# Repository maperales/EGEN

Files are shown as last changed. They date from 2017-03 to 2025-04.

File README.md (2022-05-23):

Archivos del regulador de temperatura. Electrónica General 2ºGITI Universidad de Sevilla.
=========================================================================================
En este repositorio se pueden encontrar todos los archivos necesarios para replicar el proyecto llevado a cabo en la parte 4 de la asignatura Electrónica General, de 2º curso del Grado de Ingeniera de las Tecnologías Industriales, de la Universidad de Sevilla.
  - EAGLE: archivos de Eagle para realizar la placa
  - ENERGIA: programas en energía con la funcionalidad desarrollada

En los sucesivos directorios se pueden encontrar las versiones de la placa hechas cada curso, junto con la versión del código, en caso de cambios en el código.

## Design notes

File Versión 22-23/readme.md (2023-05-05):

Nuevas versiones de la placa y del sw
=====================================
En este directorio encontraréis los ficheros del diseño realizado el curso 2022/23.

Básicamente, el cambio fundamental respecto al curso pasado es el valor (y el nombre) de las resistencias de la adaptación analógica, para ajustar al nuevo valor de la NTC utilizada (con un valor de B diferente de la de cursos anteriores). Igualmente, se han cambiado los valores de la tabla precalculada de temperatura en función del valor de ADC, para ajustar la nueva recta. Los cambios son pequeños, pero significativos.

A modo de resumen:
  - **placa2caras_23.brd**: trazado básico de pistas del diseño a partir del esquema
  - **placa2caras_23.sch**: esquema del diseño realizado
  - **placa2caras_CTO4_2023.json**: trazado de pistas definitivo, en EasyEDA, con los logos y demás.
  - **PBL_CAL.INO**: programa para calibrar la placa
  - **PBL.INO / PBL.h**: programa y librería para programar finalmente la placa

**Muy Importante: recuerda que para poder programar la placa deberás seguir los pasos que se indican en el directorio [https://github.com/maperales/EGEN/tree/master/ENERGIA]**

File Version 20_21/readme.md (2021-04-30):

Nuevas versiones de la placa y del sw
=====================================
En este directorio encontraréis los ficheros del diseño realizado el curso 2020/21. 
Como recordaréis, se ha cambiado el circuito de adaptación, usando ahora el llamado "circuito 4" desarrollado en la "tarea extra.Esto tiene una serie de
ventajas, como que se usa un único amplificador, y que éste está en modo amplificador no inversor, además de ahorrar una resistencia y simplificar el cálculo frente al circuito II. 
Por otro lado, se ha situado la NTC en la parte superior del divisor resistivo, para que el cambio de signo debido a usar un amplificador no inversor se compense. El efecto es que las ecuaciones son prácticamente iguales, y en cualquier caso al crecer la temperatura crece la tensión en el ADC. Lo único que habrá que cambiar, por tanto, es la tabla de valores de T en función de la tensión (fichero pbl.h). A modo de resumen:
  - **Placa2caras_CTO2_4.brd**: trazado de pistas del diseño
  - **Placa2caras_CTO2_4.sch**: esquema del diseño realizado
  - **placa2caras_CTO4_corregido.json**: trazado de pistas definitivo, en EasyEDA, con los logos y demás.
  - **Pbl.ino**: fichero Energia para programar el microcontrolador. Igual al del año pasado
  - **Pbl.h**: fichero de librería. Contiene la nueva tabla de valores. Éste sí ha cambiado
  - **PBL_CAL.ino**: fichero de calibración de la placa. Cambia porque incorpora en sí mismo la tabla de valores 

**Muy Importante: recuerda que para poder programar la placa deberás seguir los pasos que se indican en el directorio [https://github.com/maperales/EGEN/tree/master/ENERGIA]**

**Otra nota igual de importante: los ficheros de Eagle que se muestran aquí YA ESTÁN CORREGIDOS. Al fabricar la placa, sin embargo, se deslizó un fallo en la serigrafía y los valores de R2 y RD aparecen cambiados entre sí.**

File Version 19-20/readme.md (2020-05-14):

Nuevas versiones de la placa y del sw
=====================================
En este directorio encontraréis los ficheros del diseño realizado el curso 2019/20. 
Como recordaréis, se ha cambiado el circuito de lectura de botones, realizando la lectura ahora como una señal analógica. Esto simplifica el programa, aclarando el manejo de los botones e independizándolo de las señales K1, K2, K3 lo que permite leerlos a la velocidad que se desee. El circuito de adaptación se mantiene como en el curso pasado (circuito 2).
Por otro lado, los ficheros para la placa se han realizado en Kicad a partir de la versión en Eagle, y se incluyen en un fichero ZIP que contiene todo lo necesario (espero) para poder hacer la placa. 
A modo de resumen:
  - **PBL_1920_KiKad.zip**: Carpeta comprimida con todos los ficheros para el desarrollo del prototipo
  - **Pbl.ino**: fichero Energia para programar el microcontrolador. Igual al del año pasado
  - **Pbl.h**: fichero de librería. Contiene la nueva tabla de valores. Éste sí ha cambiado
  - **PBL_CAL.ino**: fichero de calibración de la placa. Cambia porque incorpora en sí mismo la tabla de valores 

**Muy Importante: recuerda que para poder programar la placa deberás seguir los pasos que se indican en el directorio [https://github.com/maperales/EGEN/tree/master/ENERGIA]**

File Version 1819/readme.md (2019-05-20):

Nuevas versiones de la placa y del sw
=====================================
En este directorio encontraréis los ficheros del diseño realizado el curso 2018/19. 
Como recordaréis, se ha cambiado el circuito de adaptación, usando ahora el llamado "circuito 2" en los apuntes. Esto tiene una serie de
ventajas, como que se usa un único amplificador, y que éste está en modo amplificador no inversor. El inconveniente fundamental
es que necesita una resistencia más. 
Por otro lado, se ha situado la NTC en la parte superior del divisor resistivo, para que el cambio de signo debido a usar un amplificador no inversor se compense. El efecto es que las ecuaciones son prácticamente iguales, y en cualquier caso al crecer la temperatura crece la tensión en el ADC. Lo único que habrá que cambiar, por tanto, es la tabla de valores de T en función de la tensión (fichero pbl.h). A modo de resumen:
  - **Placa2caras_CTO2_2.brd**: trazado de pistas del diseño
  - **Placa2caras_CTO2_2.sch**: esquema del diseño realizado
  - **Pbl.ino**: fichero Energia para programar el microcontrolador. Igual al del año pasado
  - **Pbl.h**: fichero de librería. Contiene la nueva tabla de valores. Éste sí ha cambiado
  - **PBL_CAL.ino**: fichero de calibración de la placa. Cambia porque incorpora en sí mismo la tabla de valores 

**Muy Importante: recuerda que para poder programar la placa deberás seguir los pasos que se indican en el directorio [https://github.com/maperales/EGEN/tree/master/ENERGIA]**

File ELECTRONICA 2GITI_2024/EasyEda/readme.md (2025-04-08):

Ficheros EasyEda
================
Se incluyen los ficheros relativos al proyecto, en formato EasyEda Pro:
  - placa_sch.epro: esquemático de la placa
  - placa_pcb.epro: PCB de la placa
  - placa_gerber.zip: ficheros de fabricación (GERBER) de la placa
  - placa_BOM.html: fichero interactivo para la identificación de componentes

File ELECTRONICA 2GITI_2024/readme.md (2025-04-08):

Electrónica 2ºGITI Plan 2024
=========================================================================================
En este repositorio se pueden encontrar todos los archivos necesarios para replicar el proyecto llevado a cabo en la parte de diseño de la asignatura Electrónica, de 2º curso del Grado de Ingeniera de las Tecnologías Industriales, plan de 2024, de la Universidad de Sevilla.
  - EasyEda: archivos de EasyEda (pro) para realizar la placa
  - CCS: programas en Code Composer Studio (C) con la funcionalidad desarrollada

En los sucesivos directorios se pueden encontrar las versiones de la placa hechas cada curso, junto con la versión del código, en caso de cambios en el código.

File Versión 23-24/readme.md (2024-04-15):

Nuevas versiones de la placa y del sw
=====================================
En esta carpeta se encuentran todos los ficheros de la última versión realizada en la asignatura de Electrónica General. Con la extinción del plan de estudios, 
esta asignatura desaparecerá el curso 2023-24, siendo esta la última vez que se monta esta placa. O no, ya veremos.

El único cambio de la placa es la posición de los transistores. Se han girado para evitar la confusión que podía producirse al estar todos los pines "en línea", lo que puede llevar a colocar mal un transistor. Mínimamente también se ha cambiado el tamaño de algún pad que resultaba difícil de soldar. Finalmente, se ha incorporado un código QR para llevar directamente a esta página.

A modo de resumen:
  - **placa2caras_23.brd**: trazado básico de pistas del diseño a partir del esquema (igual que el curso pasado)
  - **placa2caras_23.sch**: esquema del diseño realizado (igual que el curso pasado)
  - **placa2caras_CTO4_2024.json**: trazado de pistas definitivo, en EasyEDA, con los logos y demás.
  - **PBL_CAL.INO**: programa para calibrar la placa
  - **PBL.INO / PBL.h**: programa y librería para programar finalmente la placa

**Muy Importante: recuerda que para poder programar la placa deberás seguir los pasos que se indican en el directorio [https://github.com/maperales/EGEN/tree/master/ENERGIA]**

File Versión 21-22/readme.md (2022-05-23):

Nuevas versiones de la placa y del sw
=====================================
En este directorio encontraréis los ficheros del diseño realizado el curso 2021/22. 
Como recordaréis, este curso el único cambio respecto al del año pasado es la huella de un componente (el regulador de tensión) y el valor de una resistencia (la del filtro de primer orden). Por lo demás, es exactamente igual al diseño del curso pasado, por lo que el softeare no ha cambiado nada. La única novedad está en el fichero de trazado definitivo de pistas (que es donde se ha realizado el cambio de la huella) y en el esquema (cambio del valor de R8). Por tanto, no se incluyen en esta carpeta los ficheros de programación: usen los del curso anterior.  

A modo de resumen:
  - **placa2caras_22.brd**: trazado de pistas del diseño
  - **placa2caras_22.sch**: esquema del diseño realizado
  - **placa2caras_CTO4_2022.json**: trazado de pistas definitivo, en EasyEDA, con los logos y demás.

**Muy Importante: recuerda que para poder programar la placa deberás seguir los pasos que se indican en el directorio [https://github.com/maperales/EGEN/tree/master/ENERGIA]**

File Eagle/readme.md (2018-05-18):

Versión actual de los archivos de Eagle de la placa
==================================================
La placa está fabricada a doble cara, con taladros metalizados y un ancho de pista estndar de 16mils. En estas condiciones, resulta 
un poco compleja de fabricar con métodos *artesanales*. Los ficheros incluidos son:
- placa2caras_v1718.sch: esquema de la placa
- placa2caras_v1718.brd: rutado de la placa
- placa2caras_v1718_TOP.pdf: impresión de la cara superior, en pdf sin escalar ni hacer *mirror*.
- placa2caras_v1718_BOTT.pdf: impresión de la cara inferior, en pdf, sin escalar pero con  *mirror*
- placa2caras_v1718_TSILK.pdf: serigrafía de la cara superior, en pdf sin escalar ni hacer *mirror*.
- placa2caras_v1718_BSILK.pdf: serigrafí de la cara inferior, en pdf, sin escalar pero con  *mirror*
- - -
Las resistencias RD1..RD8 aparecen en el esquema como resistencias de 220 ohmios, aunque se pueden usar de 100 ohmios.

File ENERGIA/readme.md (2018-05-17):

Archivos de ENERGIA.
====================
dado lo justo que va de tamaño el programa final, se recomienda usar la versión 16 (0101E0016) de Energía. 
A partir de la siguiente se han encontrado problemas con el tamaño del código (parece que el compilador no optiimiza tanto). Dado que el código final ocupa 2011 de los 2048 bytes, cualquier cambio puede afectar. 
- - -
## Novedad: 
Se ha optimizado el código y ya cabe, incluso compilado con la versión 17. Finalmente ocupa, eso sí, 2046 de los 2048 bytes disponibles... 
- - -
La conexión entre la placa y un Launchpad G2 se hará con 4 cables hembra-hembra como se muestra en la imagen:
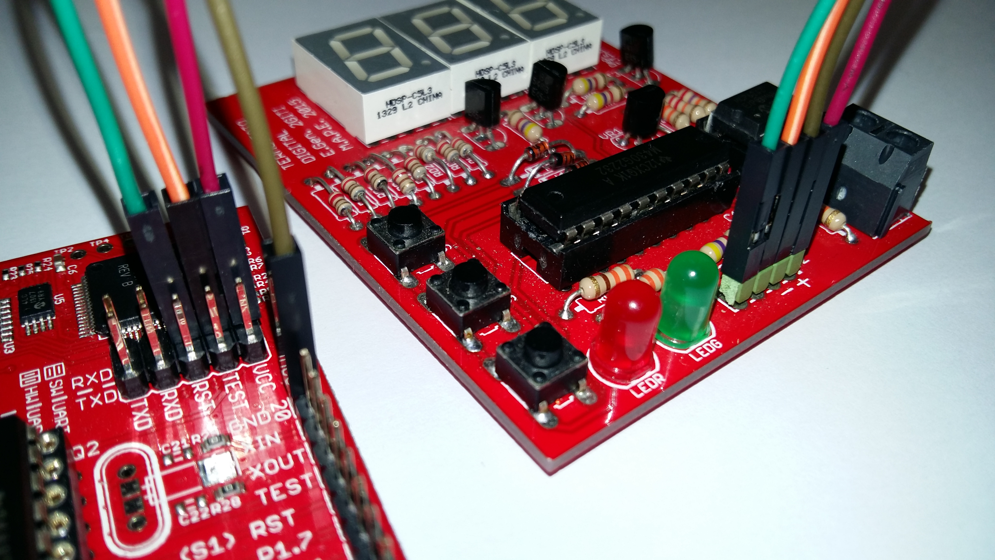
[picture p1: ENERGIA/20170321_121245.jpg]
Montaje

- - -
Para poder programar correctamente la placa, se deben seguir estos pasos:
- Descargar e instalar Energia Versión 16 [ENERGIA](http://energia.nu/download/)
- Copiar el archivo Boards.txt en el directorio \hardware\msp430\ de Energia.
- Cargar y ejecutar el Sketch PBL_CAL.ino. Anotar el offset que muestra la pantalla, y sumarlo a la variable OFFSET al principio del mismo
- Repetir el proceso hasta que el error mostrado sea 00
- Anotar el valor final de la variable OFFSET.
- Cargar el Sketch PBL.ino. En el mismo directorio debe estar el archivo PBL.h
- Modificar el valor de OFFSET según el obtenido en la calibración
- Programar la tarjeta.

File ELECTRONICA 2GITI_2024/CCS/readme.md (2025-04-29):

En este directorio se encuentran los ficheros necesarios para programar el microcontrolador
=========================================================================================
Para programar el microcontrolador se impoprtará el proyecto completo (archivo proyecto.zip). Alternativamente, se puede crear un proyecto nuevo para el microcontrolador elegido (MSP430G2232) y copiar los archivos main.c y constantes.h

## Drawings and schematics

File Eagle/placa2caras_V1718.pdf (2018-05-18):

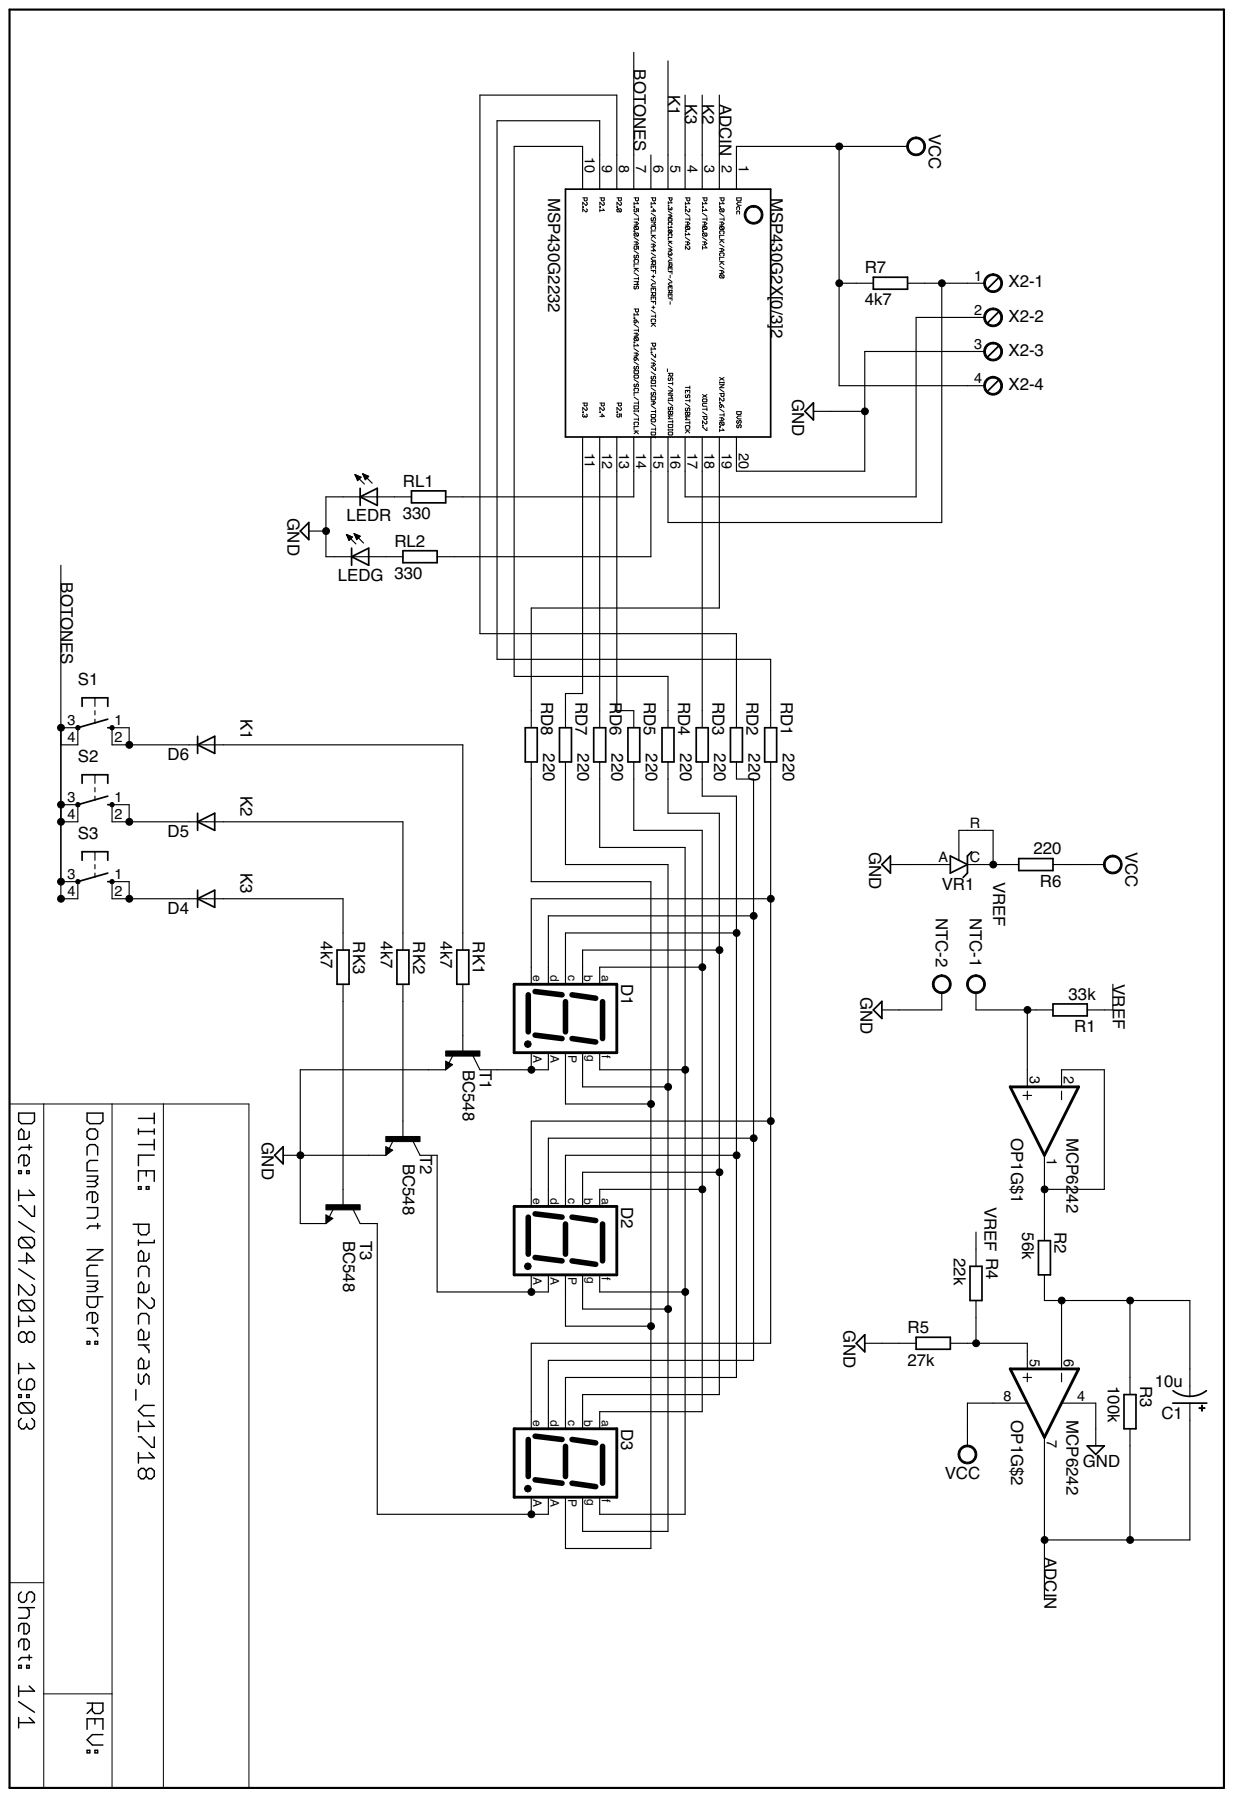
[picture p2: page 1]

MSP430G2X[0/3]2 220 220 220 220 220 220 220 220 4k7 4k7 4k7 BC548 BC548 BC548 GND GND VCC MCP6242 MCP6242 33k 56k 100k 22k 27k 220 VCC GND GND GND 10u VCC GND 330 GND 4k7 330 MSP430G2232 7654321 14151617181920 9810 131211 D1 D2 D3 RD1 RD2 RD3 RD4 RD5 RD6 RD7 RD8 RK1 RK2 RK3 T1 T2 T3 D4 D5 D6 S3 3 1 4 2 S2 3 1 4 2 S1 3 1 4 2 OP1G$1 32 1 OP1G$2 56 7 8 4R1 R2 R3 R4 R5 NTC-1 NTC-2 VR1 A CR R6 C1 LEDR LEDG RL2 R7 RL1 X2-1 1 X2-2 2 X2-3 3 X2-4 4 BOTONES BOTONES K1 K1 K2 K2 K3 K3 ADCIN ADCIN VREF VREF VREF edcba AAPgf edcba AAPgf edcba AAPgf

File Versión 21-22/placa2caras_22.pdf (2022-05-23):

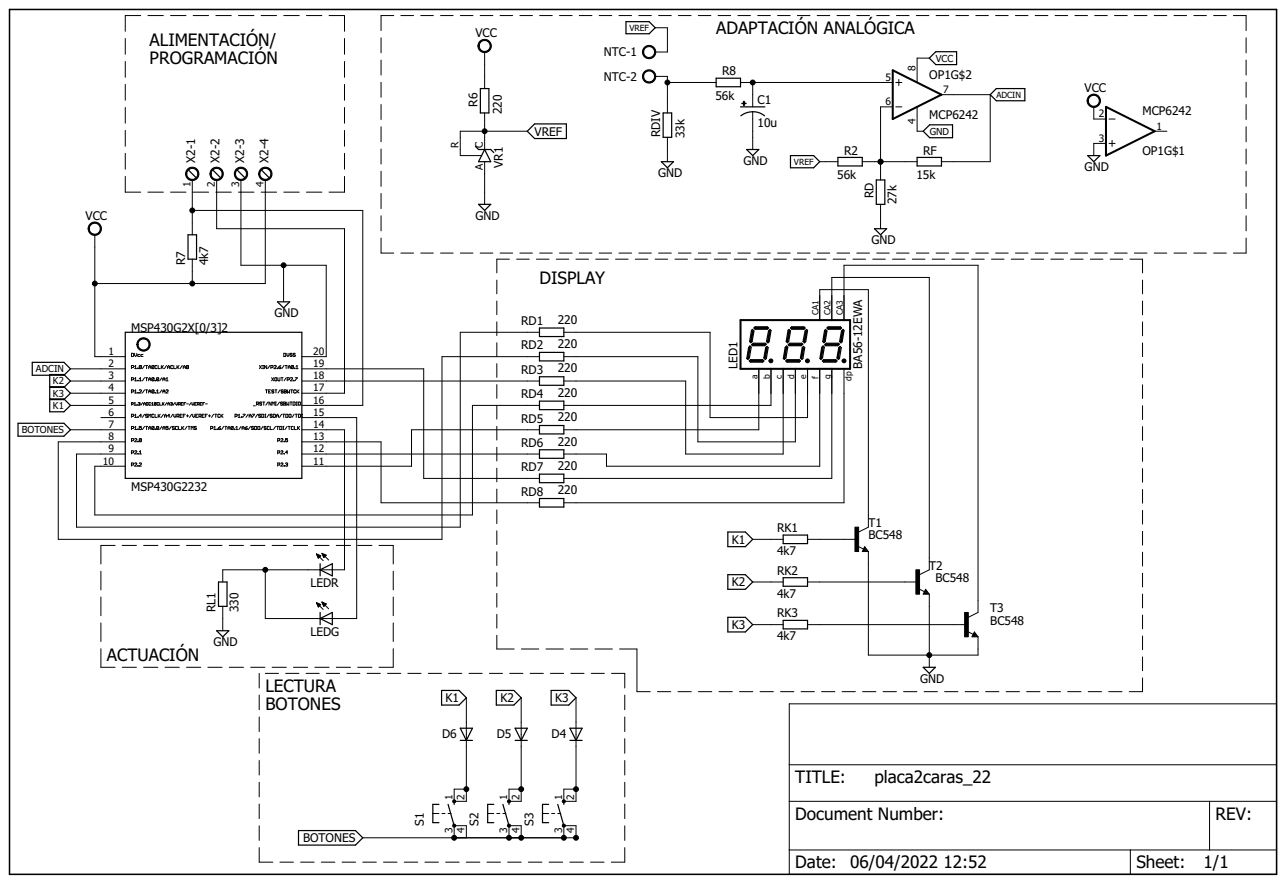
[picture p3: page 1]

18
17

9 | 12
10 | 11

Document Number: | REV:

Date: 06/04/2022 12:52 | Sheet: 1/1

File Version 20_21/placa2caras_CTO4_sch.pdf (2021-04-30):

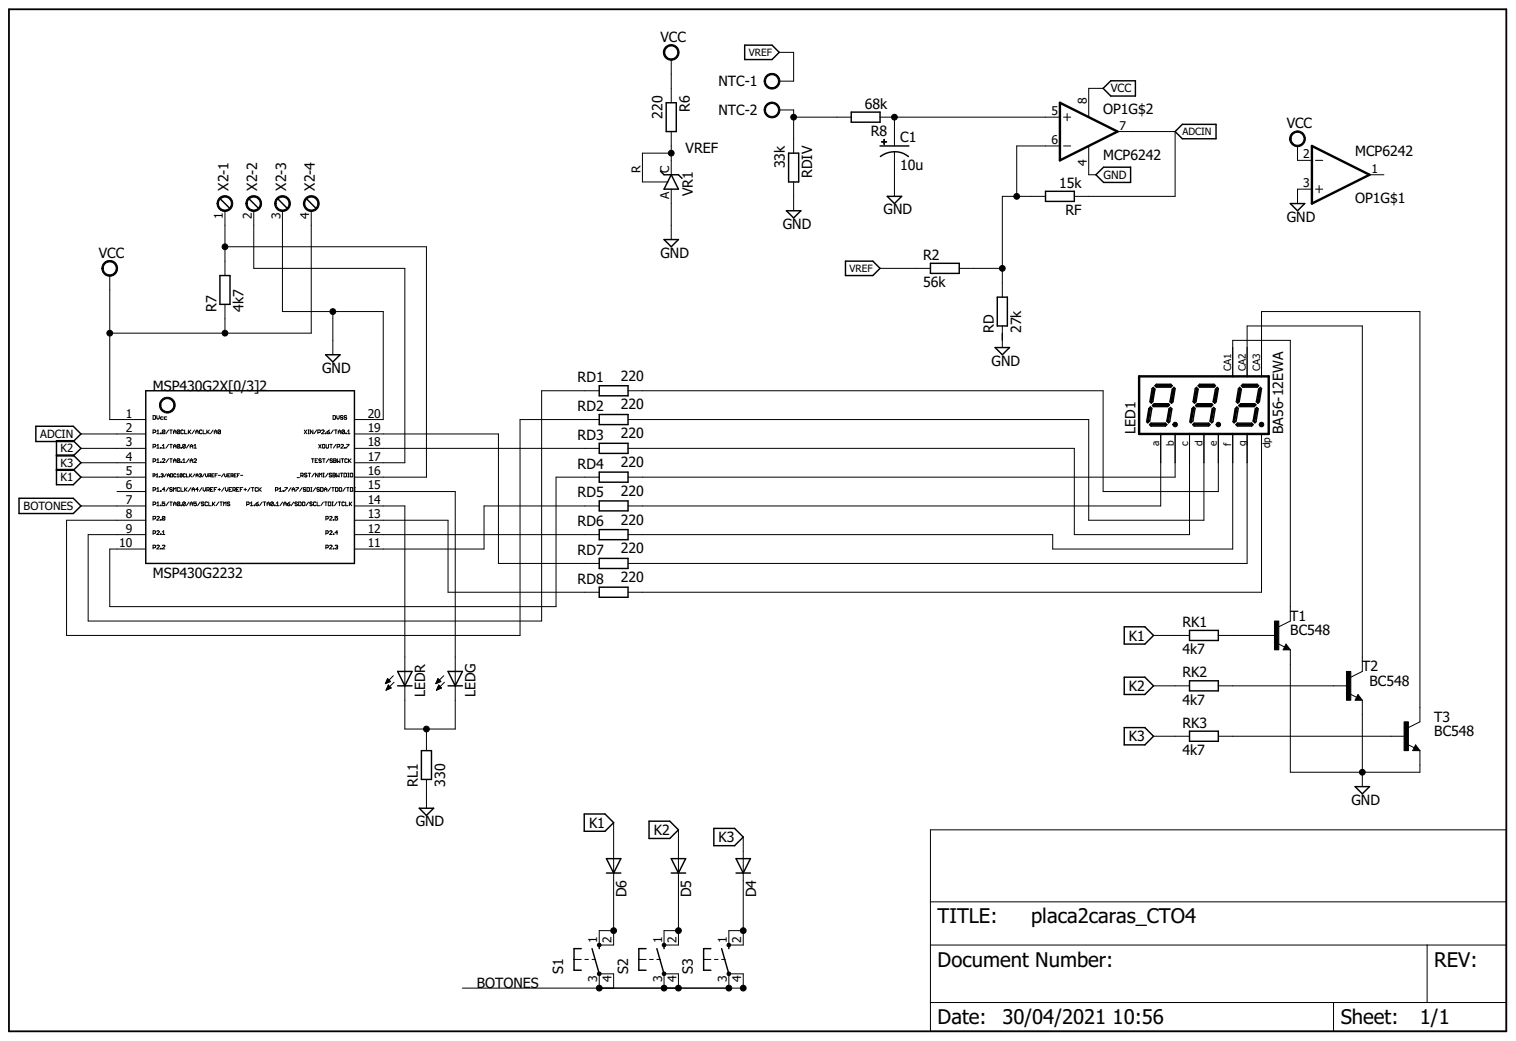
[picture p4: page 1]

18
17 | 220 RD4

Document Number: | REV:

Date: 30/04/2021 10:56 | Sheet: 1/1

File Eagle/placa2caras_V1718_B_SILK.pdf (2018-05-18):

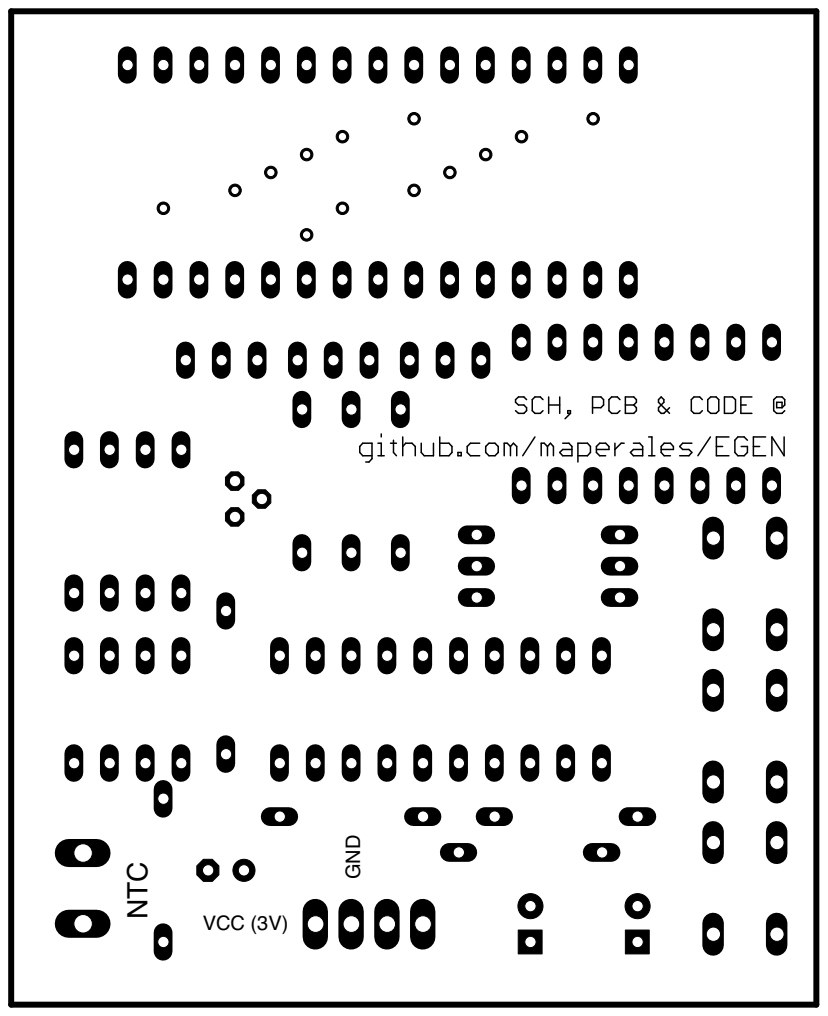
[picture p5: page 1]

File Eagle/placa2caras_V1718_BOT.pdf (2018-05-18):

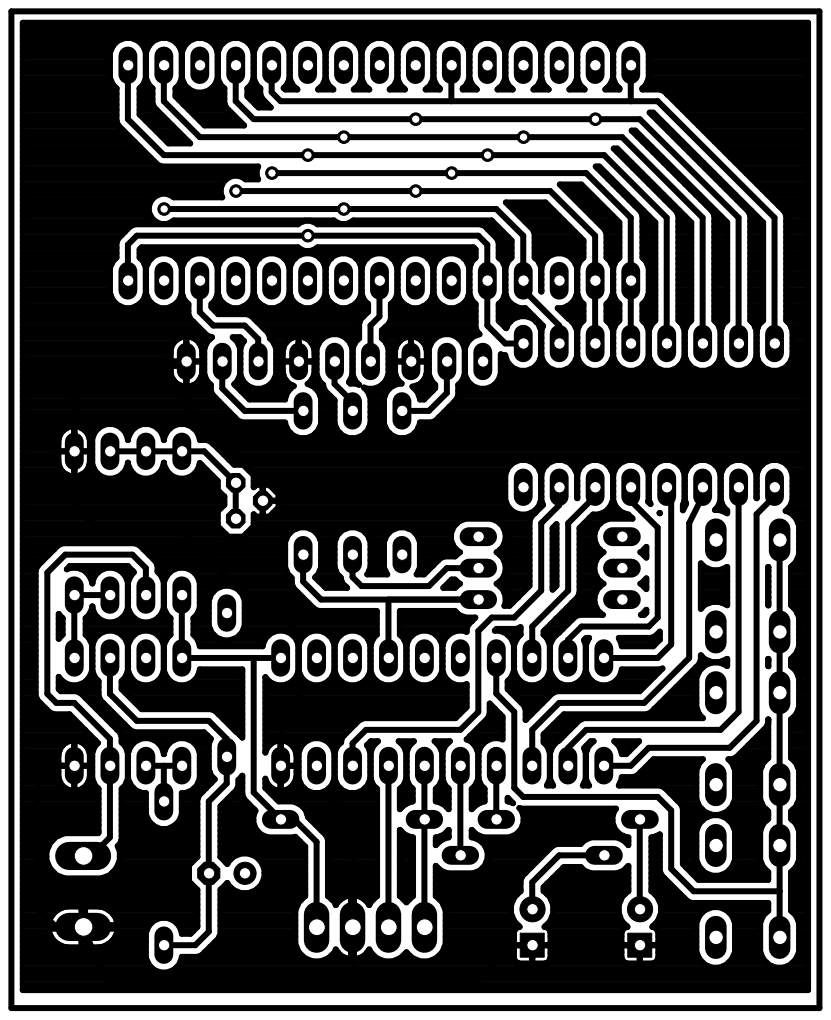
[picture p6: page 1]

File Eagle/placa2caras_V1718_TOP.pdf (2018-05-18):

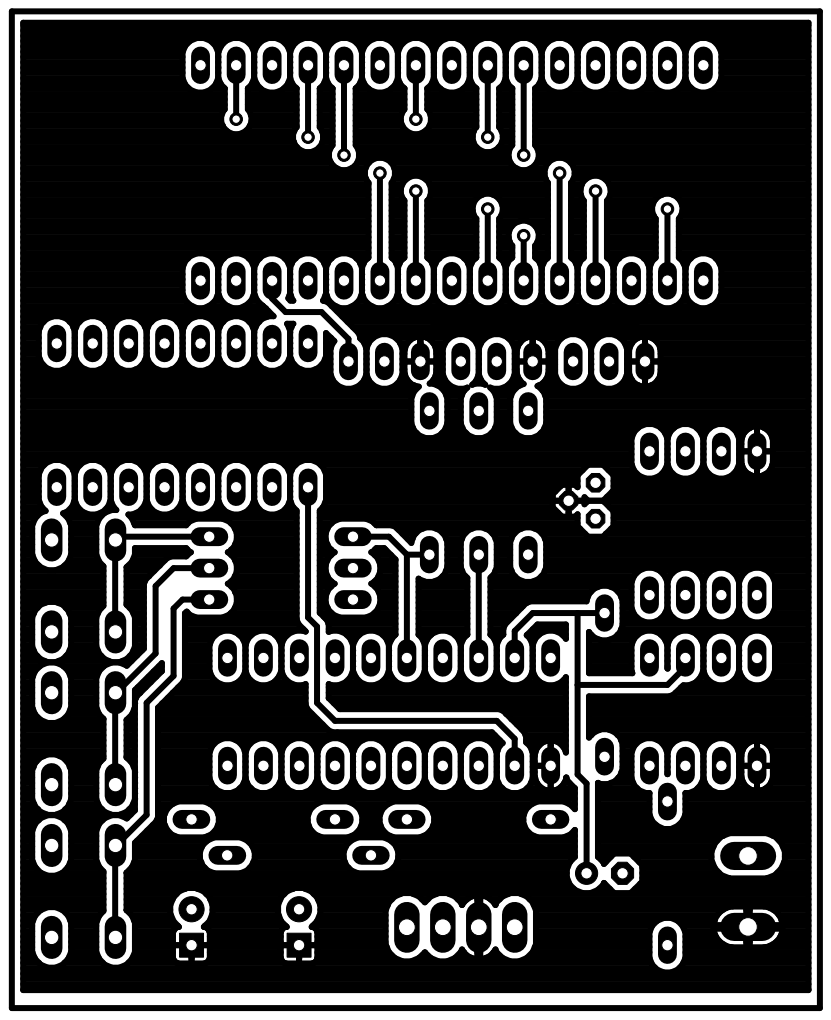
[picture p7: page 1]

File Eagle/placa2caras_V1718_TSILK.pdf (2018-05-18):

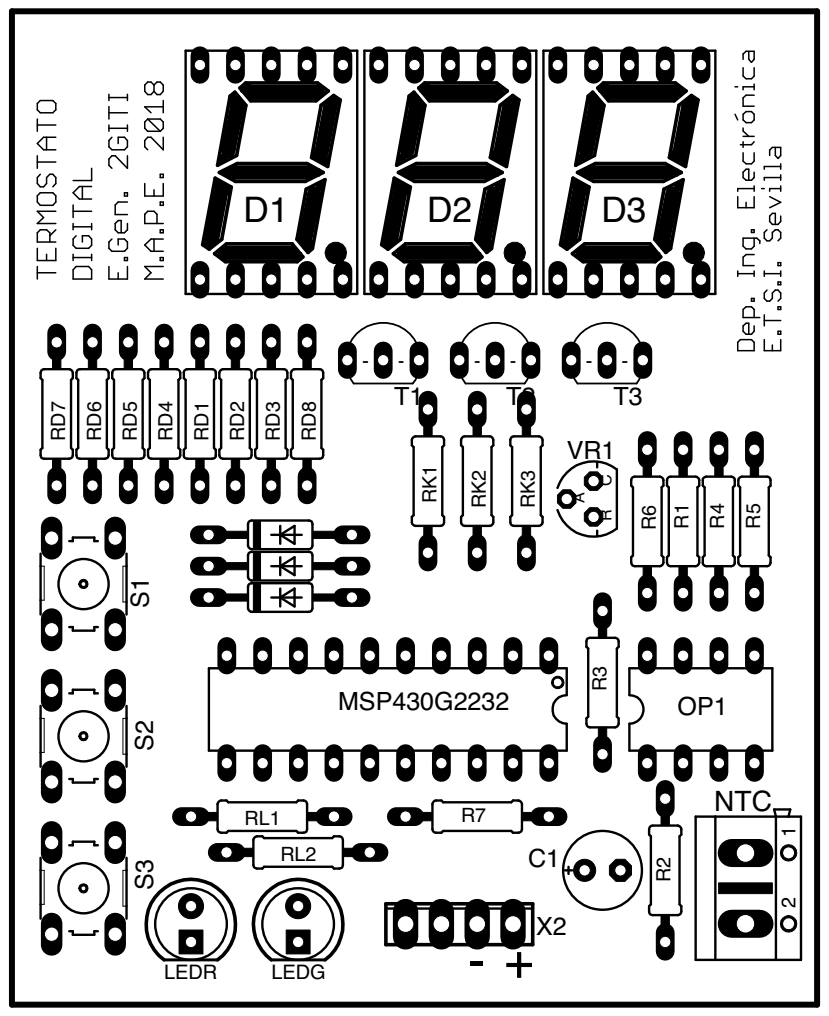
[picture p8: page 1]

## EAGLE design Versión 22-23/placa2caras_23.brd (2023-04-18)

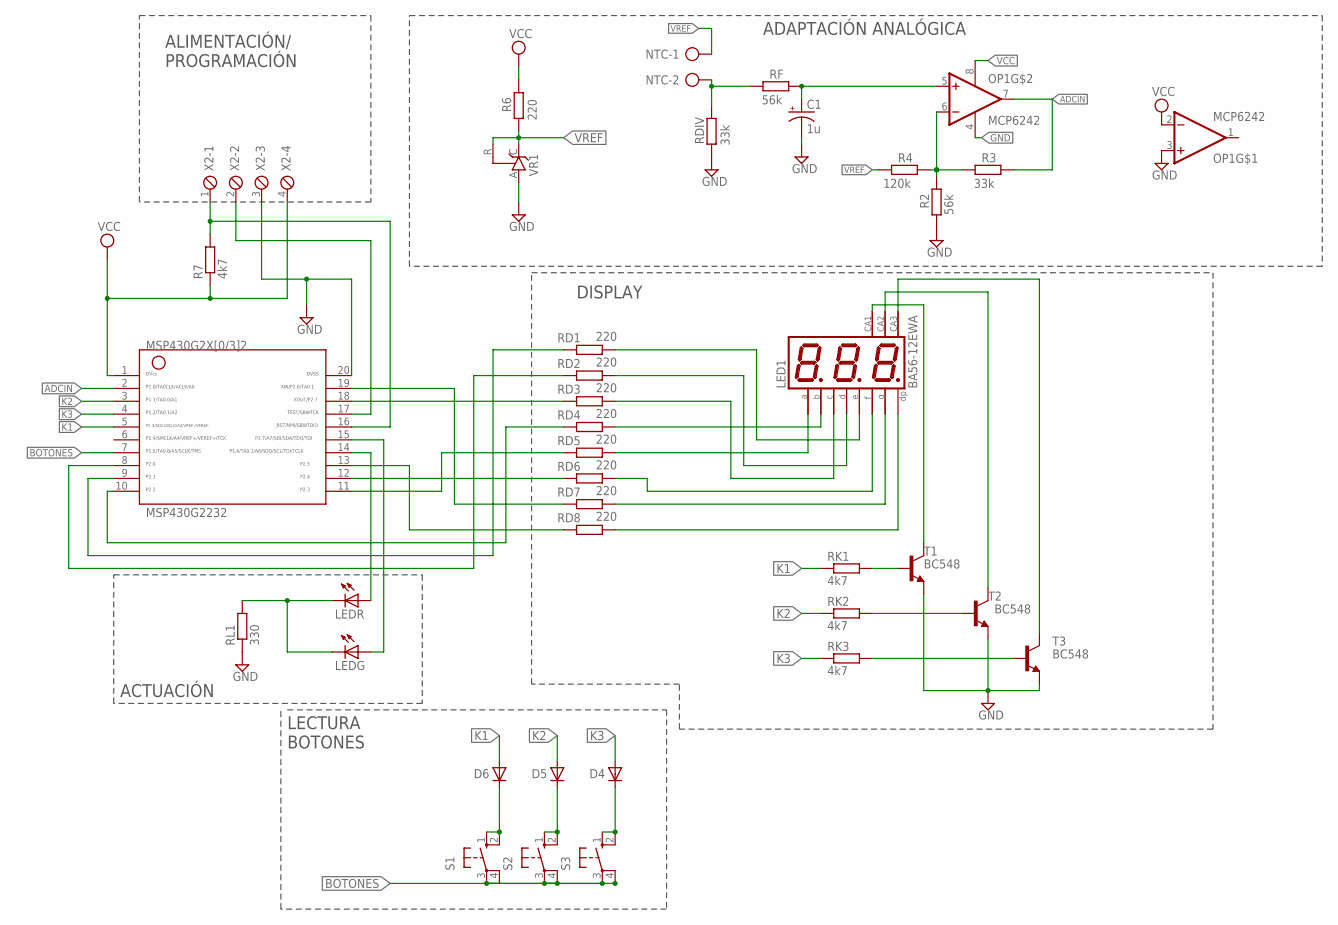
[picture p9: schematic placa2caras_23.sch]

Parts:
C1: 1u; E2,5-6E
D4, D5, D6: 1N4148DO35-10; DO35-10
LED1: BA56-12EWA; BX56-12
LEDG: LED5MM
LEDR: LED5MM
MSP430G2232: G2X[0/3]2---N20; N20
NTC: AK500/2
OP1: MCP6242; DIL8_MOD
R2: 56k; 0207/10
R3: 33k; 0207/10
R4: 120k; 0207/10
R6: 220; 0207/10
R7: 4k7; 0207/10
RD1, RD2, RD3, RD4, RD5, RD6, RD7, RD8: 220; 0207/10
RDIV: 33k; 0207/10
RF: 56k; 0207/10
RK1, RK2, RK3: 4k7; 0207/10
RL1: 330; 0207/10
S1, S2, S3: 10-XX; B3F-10XX
T1, T2, T3: BC548; TO92-EBC
VR1: TL431CLP; TO92-CLP
X2: MPT4; 4POL254

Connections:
ADCIN: MSP430G2232.2, OP1.7 (OUT), R3.1
BOTONES: MSP430G2232.7, S1.3, S1.4 (P1), S2.3, S2.4 (P1), S3.3, S3.4 (P1)
GND: C1.-, MSP430G2232.20, OP1.3 (+IN), OP1.4 (V-), R2.1, RDIV.2, RL1.1, T1.E, T2.E, T3.E, VR1.A, X2.3
K1: D6.A, MSP430G2232.5, RK1.1
K2: D5.A, MSP430G2232.3, RK2.1
K3: D4.A, MSP430G2232.4, RK3.1
unnamed: RK1.2, T1.B
unnamed: RK2.2, T2.B
unnamed: RK3.2, T3.B
unnamed: LED1.11 (A), RD5.2
unnamed: LED1.1 (E), RD1.2
unnamed: LED1.2 (D), RD2.2
unnamed: LED1.4 (C), RD3.2
unnamed: LED1.7 (B), RD4.2
unnamed: LED1.10 (F), RD6.2
unnamed: LED1.5 (G), RD7.2
unnamed: MSP430G2232.17, X2.2
unnamed: LED1.3 (DP), RD8.2
unnamed: OP1.6 (-IN), R2.2, R3.2, R4.2
unnamed: LED1.12 (CA), T1.C
unnamed: NTC.2, RDIV.1, RF.2
unnamed: LED1.9 (CA), T2.C
unnamed: C1.+, OP1.5 (+IN), RF.1
unnamed: LED1.8 (CA), T3.C
unnamed: LEDG.K (C), LEDR.K (C), RL1.2
unnamed: MSP430G2232.16, R7.2, X2.1
unnamed: MSP430G2232.19, RD7.1
unnamed: MSP430G2232.18, RD3.1
unnamed: MSP430G2232.13, RD8.1
unnamed: MSP430G2232.12, RD6.1
unnamed: MSP430G2232.11, RD5.1
unnamed: MSP430G2232.10, RD4.1
unnamed: MSP430G2232.9, RD1.1
unnamed: MSP430G2232.8, RD2.1
unnamed: D5.C, S2.1 (S), S2.2 (S1)
unnamed: D4.C, S3.1 (S), S3.2 (S1)
unnamed: D6.C, S1.1 (S), S1.2 (S1)
unnamed: LEDG.A, MSP430G2232.15
unnamed: LEDR.A, MSP430G2232.14
VCC: MSP430G2232.1, OP1.2 (-IN), OP1.8 (V+), R6.1, R7.1, X2.4
VREF: NTC.1, R4.1, R6.2, VR1.C, VR1.R

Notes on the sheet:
ADAPTACIÓN ANALÓGICA
DISPLAY
LECTURA BOTONES
ACTUACIÓN
ALIMENTACIÓN/ PROGRAMACIÓN

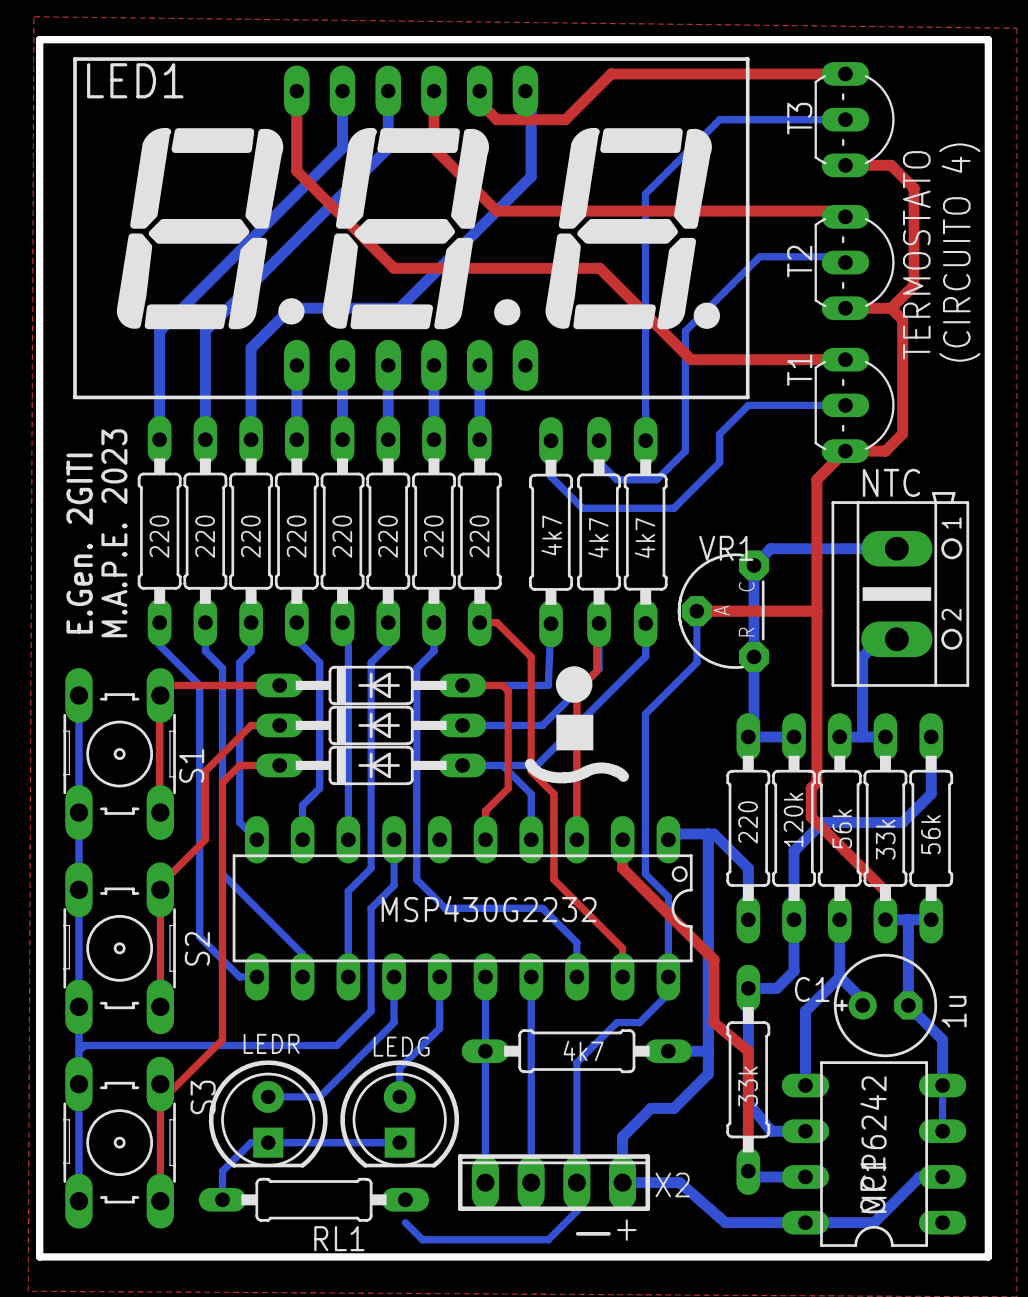
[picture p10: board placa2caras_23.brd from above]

Board: 2 copper layers, 52.7 x 67.6 mm, 37 parts (0 on the bottom side), 41 nets.

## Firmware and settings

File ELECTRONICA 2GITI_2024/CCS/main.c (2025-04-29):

#include <msp430.h> 


/**
 * main.c
 */

int  OFFSET = -5;  //Variable de calibracion
//------------------------------

#include "constantes.h"

/***********************************************
VECTOR CON LAS DIRECCIONES DE LOS PINES DEL P2,
ORDENADAS, PARA USARLO DE MANERA ITERATIVA
P1.3: g
P1.4: c
P1.5: dp
P2.0: d
P2.1: e
P2.2: b
P2.3: a
P2.4: f
P1.0: K1
P1.1: K2
P1.2: K3
P2.6: LEDG
P2.7: LEDR
DIG:[p15, p14,p13, p24, p23, p22, p21, p20]
************************************************/



void Set_clk(void){
    BCSCTL2 = SELM_0 | DIVM_0 | DIVS_0;
    if (CALBC1_16MHZ != 0xFF) {
                __delay_cycles(100000);
                DCOCTL = 0x00;
                BCSCTL1 = CALBC1_16MHZ;     /* Set DCO to 16MHz */
                DCOCTL = CALDCO_16MHZ;
            }
    BCSCTL1 |= XT2OFF | DIVA_0;
    BCSCTL3 = XT2S_0 | LFXT1S_2 | XCAP_1;
}


char ciclo=0;
char numero=0;
int t=0;
int T;
char PER=20;
int TREF=210;
int Vin=0;
int DIG[3];
int BOT[]={ 0,0,0};
int Trep=0;

char Estado_Display=0;
char DC=9;


void saca_d(int num)    // Descompone un nº en 3 digitos y guarda la representación en DIG
{
  int i=0;
  if(num<0)
    {
      num=-num;
      DIG[2]=DISPL[18];
    }
  else
      {
      while(num>=100) {

    num-=100;
    i++;
  }   // Dividir entre 100 por restas sucesivas
  DIG[2]=DISPL[i];
      }
  i=0;
  while(num>=10){
    num-=10;
    i++;
  }      // Dividir entre 10 por restas sucesivas
  DIG[1]=DISPL[i]+0x80;
  DIG[0]=DISPL[num];  //Punto decimal en el 2Âº digito
}




int lee_ch(char canal){
    ADC10CTL0 &= ~ENC;                  //deshabilita el ADC
    ADC10CTL1&=(0x0fff);                //Borra canal anterior
    ADC10CTL1|=canal<<12;               //selecciona nuevo canal
    ADC10CTL0|= ENC;                    //Habilita el ADC
    ADC10CTL0|=ADC10SC;                 //Empieza la conversión
while(ADC10CTL1&ADC10BUSY);
return(ADC10MEM);                   //Devuelve valor leido
    }

int valor;

void lee_botones(void)
{
    valor=lee_ch(7);
    if(valor>480) //Mirar si BOT1 está apretado
    {
        BOT[2]++;
        if(valor>605) //Mirar si B1+B2
        {
            BOT[1]++;
            if(valor>640)
            {
                BOT[0]++; //Mirar si B1+B2+B3
            }
            else
            {
                BOT[0]=0;
            }
        }
        else
        {
            BOT[1]=0;
            if(valor>550)
            {
                BOT[0]++; //Mirar si B1+B3
            }
            else
            {
                BOT[0]=0;
            }
        }
    }
    else  //B1=0
    {
        BOT[2]=0;
        if(valor>320) //Mirar si B2
        {
            BOT[1]++;
            if(valor>420){
                BOT[0]++; //Mirar si B2+B3
            }
            else
            {
                BOT[0]=0;
            }
        }
        else
        {
            BOT[1]=0;
            if(valor>200)
            {
                BOT[0]++; //Mirar si B3
            }
            else
            {
                BOT[0]=0;
            }

        }
    }

}

char t_bot=0;
unsigned char bot_s=0;
int main(void)
{
    unsigned char idx;       // idx: 5MSB del dato (indice para interpolar)
    unsigned char resto;   // resto: 5LSB del dato
    int T;     // T: la que sale de la tabla
    int  Tlineal;

    WDTCTL = WDTPW | WDTHOLD;	// stop watchdog timer
    Set_clk();

    P2DIR=0xFF;        // P2: Salida entero: a, b, d, e, f, LR, LV.
    P2OUT =0;           //Todo apagado
    P2SEL=0;
    P2SEL2=0;
    P1DIR=0x3F;        // P1: salidas para K1, K2, K3, g,c,dp.


    ADC10CTL0 &= ~ENC;      //deshabilita ADC
    ADC10CTL0 = ADC10ON | ADC10SHT_3 | REFON |REF2_5V |SREF_1; //enciende ADC, S/H lento, REF:2.5V, SIN INT
    ADC10CTL1 = CONSEQ_0 | ADC10SSEL_0 | ADC10DIV_7 | SHS_0 | INCH_0;
    //Modo simple, reloj ADC, sin subdivision, Disparo soft, Canal 0
    ADC10AE0 = BIT6+BIT7; //habilita los canales indicados
    ADC10CTL0 |= ENC; //Habilita el ADC
    TACTL= MC_1|TASSEL_2|ID_3; //2MHz
    TACCTL0=CCIE;
    TACCR0=10000;    //5ms
    TACCR1=9990;
    TACCTL1=CCIE;

    __bis_SR_register(GIE);


    while(1)
    {
        LPM0;
        P1OUT &=0Xf8; // ~(BIT1+BIT2+BIT0);
        P2OUT &=0xE0;  //borra pines 0 a 4
        P2OUT |=DIG[ciclo]&0x1F;
        P1OUT &=0xC7; //borra pines 3, 4, 5
        P1OUT |=(DIG[ciclo]&0xE0)>>2;
        P1OUT |=KK[ciclo];
        ciclo++;
        if (ciclo==3)
        {   // Si ya se ha pasado por los tres:
            ciclo=0;
            t++;   //cada 15ms
            lee_botones();
            if(!(BOT[0]+BOT[1]+BOT[2]))
            {
                Estado_Display=0;
                Trep++;
                PER=20;
                if(Trep>TREPOSO)    // Si se supera el tiempo de reposo sin pulsaciones
                {
                    Estado_Display=5;    // Entra en reposo
                    Trep=TREPOSO;
                }
            }
            else
            {
                Trep=0;
                if(!(BOT[1]))  //B2 no pulsado
                {
                    if(BOT[0]==BOT_PULS)   //B1 solo
                    {
                        if(TREF>0)TREF--;
                        Estado_Display=1;
                    }
                    if(BOT[0]>BOT_PULS_LARGA)  //B1 puls. larga
                    {
                        if(TREF>0)TREF--;
                        PER=5;
                        Estado_Display=1;
                    }

                    if(BOT[2]==BOT_PULS)   //B3 solo
                    {
                        if(TREF<500)TREF++;
                        Estado_Display=1;
                    }
                    if(BOT[2]>BOT_PULS_LARGA)  //B3 puls. larga
                    {
                        if(TREF<500)TREF++;
                        PER=5;
                        Estado_Display=1;
                    }
                }
                if(BOT[1]>=BOT_PULS)   //B2 pulsado
                {
                    if(BOT[0]==BOT_PULS && Estado_Display!=6)    //B1+B2: decrementa brillo
                    {
                        if(DC>1)DC--;                     // Decrementa brillo
                        TA0CCR1=DC*999;
                        Estado_Display=6;
                    }
                    else if(BOT[2]==BOT_PULS && Estado_Display!=6)    //B3+B2: incrementa brillo
                    {
                        if(DC<9)DC++;                     // Decrementa brillo
                        TA0CCR1=DC*999;
                        Estado_Display=6;
                    }
                    else if(BOT[1]>BOT_PULS_MUY_LARGA && (!(BOT[0]+BOT[2])))   //B2 puls muy larga (E2GITI)
                    {
                        if(Estado_Display<10) Estado_Display=10;
                        PER=70;
                    }
                    else if(BOT[1]==BOT_PULS)
                    {
                        Estado_Display=2; PER=70;
                    }
                }
            }
            if(t>=PER)
            {       // PER=20
                // CADA (20*3*5=300)ms se rehacen las medidas

                Vin+=lee_ch(6);  // Valor medido mÃ¡s error calculado
                Vin=Vin>>1;
                Vin=lee_ch(6);
                Vin=Vin-OFFSET;
                if(Vin<0)Vin=0;
                idx=Vin>>5;       // idx: 5MSB del dato (indice para interpolar)
                resto=Vin-(idx*32);   // resto: 5LSB del dato
                T=T_tab[idx];     // T: la que sale de la tabla
                // Tlineal: incremento sobre T (interp. lineal)
                Tlineal=((T_tab[idx+1]-T_tab[idx])*resto)>>5;
                T=T+Tlineal;

                if(T>(TREF+10))  P2OUT |=BIT7;     //Enciende LedV
                if(T<(TREF-5))   P2OUT &=~BIT7;    //Apaga LedV
                if(T>(TREF+5))   P2OUT  &=~BIT6;   //Apaga LedR
                if(T<(TREF-10))  P2OUT |=BIT6;     //Enciende LedR


                switch(Estado_Display)
                {  // Qué se debe mostrar por el display
                case 0:            // 0: la temperatura actual
                    saca_d(T);

                    break;
                case 1:           // 1:la Temp. de referencia
                    saca_d(TREF);

                    Estado_Display=0;
                    break;
                case 2:          // 2: mensaje REF
                    DIG[2]=DISPL[10];
                    DIG[1]=DISPL[11];
                    DIG[0]=DISPL[12];
                    Estado_Display=3;
                    break;
                case 3:          // 3: Temperatura de Referencia
                    saca_d(TREF);
                    Estado_Display=2;

                    break;
                case 5:           // 5: Apagar los displays
                    DIG[2]=0;
                    DIG[1]=0;
                    DIG[0]=0;
                    break;
                case 6:            // 6: mostrar intensidad luminosa
                    DIG[2]=DISPL[1];     // I
                    DIG[1]=DISPL[14];    // n
                    DIG[0]=DISPL[DC];    // DC (entre 0 y 9)
                    break;
                case 10:   //E.2G
                    DIG[2]=DISPL[11]+0x80; ;     // E.
                    DIG[1]=DISPL[2];            // 2
                    DIG[0]=DISPL[19];            // G
                    Estado_Display=11;
                    break;

                case 11: // 2GI
                    DIG[2]=DISPL[2];    // 2
                    DIG[1]=DISPL[19];   // G
                    DIG[0]=DISPL[1];    // I
                    Estado_Display=12;
                    break;
                case 12:   //GIt
                    DIG[2]=DISPL[19];           // G
                    DIG[1]=DISPL[1];           // I
                    DIG[0]=DISPL[20];   // t
                    Estado_Display=13;
                    break;

                case 13:   //ItI.
                    DIG[2]=DISPL[1];           // I
                    DIG[1]=DISPL[20];           // t
                    DIG[0]=DISPL[1]+0x80; ;    // I
                    Estado_Display=10;
                    break;

                }
                t=0;
            }     //fin bucle PER
        }
    }    //fin ciclo
}    //Fin LooP





#pragma vector=TIMER0_A0_VECTOR
__interrupt void timer_5ms(void)
{
    LPM0_EXIT;

}

#pragma vector=TIMER0_A1_VECTOR
__interrupt void pwm_manual(void)
{
    P1OUT &=~(BIT1+BIT2+BIT0);
    TAIV=0;
}

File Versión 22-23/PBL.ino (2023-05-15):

//COPIAR AQUÍ EL VALOR OBTENIDO EN LA CALIBRACIÓN
//------------------------------
int OFFSET=-13;
//------------------------------

#include "pbl.h"

void setup()         // Programada en Bajo Nivel para que quepa
{
  // for(int i=0;i<8;i++) pinMode(P_2[i],OUTPUT);
  P2DIR=0xFF;        // P2: Salida entero (display)
  P2SEL=0;
  P2SEL2=0;  
  /*pinMode(3,OUTPUT);
   pinMode(4,OUTPUT);
   pinMode(5,OUTPUT);
   pinMode(14,OUTPUT);
   pinMode(15,OUTPUT);
   pinMode(7,INPUT_PULLDOWN);*/
  P1DIR=0xDE;        // P1: salidas para K1, K2, K3, AA y CAL
  P1OUT&=~BIT5;      // P1.5: entrada con Pull_down
  P1REN=BIT5;
  analogReference(INTERNAL2V5); //Referencia del ADC: 2,5V
} 

byte ciclo=0;
byte numero=0;
int t=0;
int T;
byte PER=20;
int TREF=210;
int Vin=0;
int DIG[3];
int BOT[]={
  0,0,0};
int Trep=0;

byte Estado_Display=0;
byte DC=5;


void saca_d(int num)    // Descompone un nº en 3 digitos y guarda la representación en DIG
{
  int i=0;
  if(num<0)
  {
    num=-num;
    DIG[2]=DISPL[18];
  }
  else{
  while(num>=100) {
    num-=100;
    i++;
  }   // Dividir entre 100 por restas sucesivas
  DIG[2]=DISPL[i]; 
  }
  i=0;
  while(num>=10){
    num-=10;
    i++;
  }      // Dividir entre 10 por restas sucesivas
  DIG[1]=DISPL[i]+0x20; 
  DIG[0]=DISPL[num];  //Punto decimal en el 2º digito
}

void loop()
{
  delay(DC);        //  Tiempo en ON (display anterior). entre 0 y 5ms
  digitalWrite(3,LOW);
  digitalWrite(4,LOW);
  digitalWrite(5,LOW);
  P2OUT=DIG[ciclo];  
  delay(5-DC);      // Tiempo en OFF, entre 0 y 5 ms
//  P1OUT|=BIT4;      // Comienzo ciclo: se usa para medir tiempo de actividad
  digitalWrite(KK[ciclo],HIGH);  //Enciendo el K correspondiente
  //if(digitalRead(7)){            //Miro boton CAMBIADO PARA AHORRAR POR...
  if(P1IN&BIT5){            //Miro boton

    BOT[ciclo]++; 
    Trep=0;   
  }
  else{
    BOT[ciclo]=0;
  }

  ciclo++;
  if (ciclo==3){   // Si ya se ha pasado por los tres:
    ciclo=0;
    t++;
    if(!(BOT[0]+BOT[1]+BOT[2]))
    { 
      Estado_Display=0; 
      Trep++; 
      PER=20;
      if(Trep>TREPOSO)    // Si se supera el tiempo de reposo sin pulsaciones 
      {
        Estado_Display=5;    // Entra en reposo
        Trep=TREPOSO;  
      }
    }
    else{
      if(BOT[1]>=5*BOT_PULS_LARGA && (BOT[0]+BOT[2])==0)
      {
        if(Estado_Display<10) Estado_Display=10;
        PER=50;
      }
      if(BOT[2]==BOT_PULS)
      {
        if(BOT[1]>0){
          BOT[1]=1;
          if(DC<5)DC++;                    // Incrementa brillo
          Estado_Display=6;
        }
        else{
          TREF++;
          Estado_Display=1;
        }
      }
      if(BOT[0]==BOT_PULS)
      {
        if(BOT[1]>0){
          BOT[1]=1;
          if(DC>0)DC--;                     // Decrementa brillo
          Estado_Display=6;
        }
        else
        {
          TREF--;
          Estado_Display=1;
        }

      }
      if(BOT[1]==BOT_PULS && (BOT[0]+BOT[2])==0)
      {
        Estado_Display=2; PER=50;
      }
      if(BOT[1]==0){
        if(BOT[0]>=BOT_PULS_LARGA)
        {
          TREF--;
          Estado_Display=1;
          PER=5;
        }
        if(BOT[2]>=BOT_PULS_LARGA)
        {
          TREF++;
          Estado_Display=1;
          PER=5;
        }
      }
    }

    if(t>=PER){       // PER=20 
                      // CADA (20*3*5=300)ms se rehacen las medidas

      Vin=(Vin+analogRead(A0)-OFFSET)>>1;  // Valor medido más error calculado (filtrado)
      int idx=Vin>>5;		// idx: 5MSB del dato (indice para interpolar)
      int resto=Vin-(idx*32);	// resto: 5LSB del dato
      int T=T_tab[idx];		// T: la que sale de la tabla
      // Tlineal: incremento sobre T (interp. lineal)
      int Tlineal=((T_tab[idx+1]-T_tab[idx])*resto)>>5;
      T=T+Tlineal;

      if(T>(TREF+20)) digitalWrite(15,HIGH);
      if(T<(TREF-5))  digitalWrite(15,LOW);
      if(T>(TREF+5))  digitalWrite(14,LOW);
      if(T<(TREF-20)) digitalWrite(14,HIGH);

      switch(Estado_Display){  // Qué se debe mostrar por el display
      case 0:            // 0: la temperatura actual
        saca_d(T);

        break;
      case 1:           // 1:la Temp. de referencia
        saca_d(TREF);

        Estado_Display=0;
        break;
      case 2:          // 2: mensaje REF
        DIG[2]=DISPL[10];
        DIG[1]=DISPL[11];
        DIG[0]=DISPL[12];
        Estado_Display=3;
        break;
      case 3:          // 3: Temperatura de Referencia
        saca_d(TREF);
        Estado_Display=2;

        break;
      case 5:           // 5: Apagar los displays
        DIG[2]=0;
        DIG[1]=0;
        DIG[0]=0;
        break;
      case 6:            // 6: mostrar intensidad luminosa
        DIG[2]=DISPL[1];     // I
        DIG[1]=DISPL[14];    // n
        DIG[0]=DISPL[DC];    // DC (entre 0 y 5)
        break; 
     case 10:
        DIG[2]=DISPL[11]+0x20; ;     // E.
        DIG[1]=DISPL[19];            // G
        DIG[0]=DISPL[11];            // E
        Estado_Display=11;
        break; 
      case 11:
        DIG[2]=DISPL[19];           // G
        DIG[1]=DISPL[11];           // E
        DIG[0]=DISPL[14]+0x20; ;    // n.
        Estado_Display=10;
        break; 


      }

      t=0;

    }     //fin bucle PER

  }    //fin ciclo
//  P1OUT&=~BIT4;// Fin ciclo: se usa para medir tiempo de actividad

}    //Fin LooP
